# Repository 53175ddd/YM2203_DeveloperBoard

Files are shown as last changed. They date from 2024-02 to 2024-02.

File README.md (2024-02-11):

# YM2203_DeveloperBoard

YAMAHA 製 FM 音源 IC YM2203 用の SPI インターフェース開発ボード

# 部品表

| 部品番号 | 部品名 | 秋月リンク |
|:----|:----|:----:|
| C1 ~ C3 | 0.1uF | <https://akizukidenshi.com/catalog/g/g110147/> |
| C4 | 10uF | <https://akizukidenshi.com/catalog/g/g117897/> |
| C5, C6 | 47uF | <https://akizukidenshi.com/catalog/g/g110270/> |
| R1 ~ R10 | 10kΩ | <https://akizukidenshi.com/catalog/g/g125103/> |
| U1 | YM2203 | - |
| U2 | YM3014B | - |
| U3 | MCP23S17 | <https://akizukidenshi.com/catalog/g/g110644/> |
| U4, U5 | NJM4558DD | <https://akizukidenshi.com/catalog/g/g111236/> |
| U6 | 1MHz Osc | <https://akizukidenshi.com/catalog/g/g110385/> |

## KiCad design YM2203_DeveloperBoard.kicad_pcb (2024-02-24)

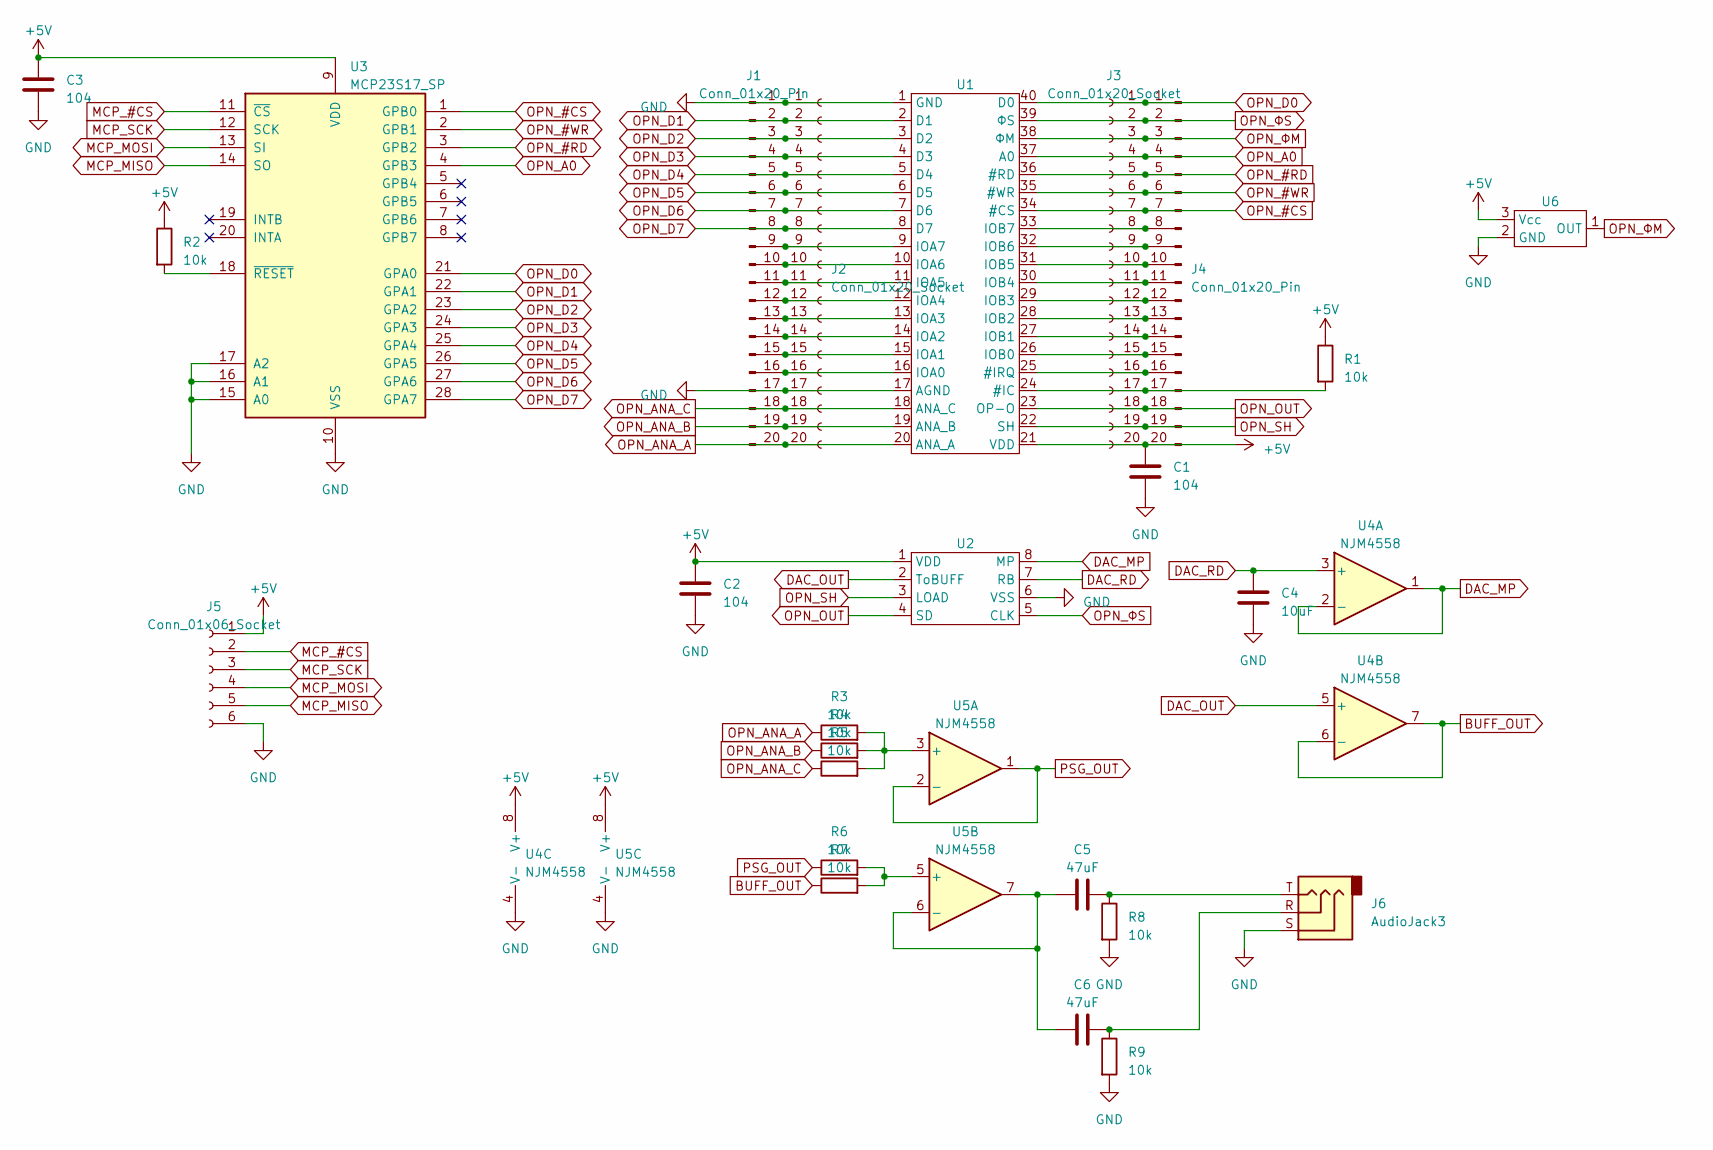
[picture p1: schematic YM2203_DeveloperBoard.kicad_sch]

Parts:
C1, C2, C3: 104; C_Disc_D5.0mm_W2.5mm_P5.00mm
C4: 10uF; CP_Radial_D6.3mm_P2.50mm
C5, C6: 47uF; CP_Radial_D6.3mm_P2.50mm
J1, J4: Conn_01x20_Pin; PinHeader_1x20_P2.54mm_Vertical
J2, J3: Conn_01x20_Socket; PinSocket_1x20_P2.54mm_Vertical
J5: Conn_01x06_Socket; PinSocket_1x06_P2.54mm_Vertical
J6: AudioJack3; Jack_3.5mm_Switronic_ST-005-G_horizontal
R1, R2, R3, R4, R5, R6, R7, R8, R9: 10k; R_Axial_DIN0207_L6.3mm_D2.5mm_P10.16mm_Horizontal
U1: DIP-40_W15.24mm_Socket
U2: DIP-8_W7.62mm_Socket
U3: MCP23S17_SP; DIP-28_W7.62mm
U4, U5: NJM4558; DIP-8_W7.62mm_Socket
U6: TO-92_Inline_Wide

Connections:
+5V: C1.1, C2.1, C3.1, J3.20, J4.20, J5.1, R1.1, R2.1, U1.21 (VDD), U2.1 (VDD), U3.9 (VDD), U4.8 (V+), U5.8 (V+), U6.3 (Vcc)
BUFF_OUT: R7.1, U4.6 (-), U4.7
DAC_MP: U2.8 (MP), U4.1, U4.2 (-)
DAC_OUT: U2.2 (ToBUFF), U4.5 (+)
DAC_RD: C4.1, U2.7 (RB), U4.3 (+)
GND: C1.2, C2.2, C3.2, C4.2, J1.1, J1.17, J2.1, J2.17, J5.6, J6.S, R8.2, R9.2, U1.1 (GND), U1.17 (AGND), U2.6 (VSS), U3.10 (VSS), U3.15 (A0), U3.16 (A1), U3.17 (A2), U4.4 (V-), U5.4 (V-), U6.2 (GND)
MCP_#CS: J5.2, U3.11 (~CS)
MCP_MISO: J5.5, U3.14 (SO)
MCP_MOSI: J5.4, U3.13 (SI)
MCP_SCK: J5.3, U3.12 (SCK)
unnamed: C5.2, J6.T, R8.1
unnamed: C6.2, J6.R, R9.1
unnamed: J1.9, J2.9, U1.9 (IOA7)
unnamed: J1.10, J2.10, U1.10 (IOA6)
unnamed: J1.11, J2.11, U1.11 (IOA5)
unnamed: J1.12, J2.12, U1.12 (IOA4)
unnamed: J1.13, J2.13, U1.13 (IOA3)
unnamed: J1.14, J2.14, U1.14 (IOA2)
unnamed: J1.15, J2.15, U1.15 (IOA1)
unnamed: J1.16, J2.16, U1.16 (IOA0)
unnamed: J3.8, J4.8, U1.33 (IOB7)
unnamed: J3.9, J4.9, U1.32 (IOB6)
unnamed: J3.10, J4.10, U1.31 (IOB5)
unnamed: J3.11, J4.11, U1.30 (IOB4)
unnamed: J3.12, J4.12, U1.29 (IOB3)
unnamed: J3.13, J4.13, U1.28 (IOB2)
unnamed: J3.14, J4.14, U1.27 (IOB1)
unnamed: J3.15, J4.15, U1.26 (IOB0)
unnamed: J3.16, J4.16, U1.25 (#IRQ)
unnamed: J3.17, J4.17, R1.2, U1.24 (#IC)
unnamed: R2.2, U3.18 (~RESET)
unnamed: R3.2, R4.2, R5.2, U5.3 (+)
unnamed: R6.2, R7.2, U5.5 (+)
unnamed: C5.1, C6.1, U5.6 (-), U5.7
OPN_#CS: J3.7, J4.7, U1.34 (#CS), U3.1 (GPB0)
OPN_#RD: J3.5, J4.5, U1.36 (#RD), U3.3 (GPB2)
OPN_#WR: J3.6, J4.6, U1.35 (#WR), U3.2 (GPB1)
OPN_A0: J3.4, J4.4, U1.37 (A0), U3.4 (GPB3)
OPN_ANA_A: J1.20, J2.20, R3.1, U1.20 (ANA_A)
OPN_ANA_B: J1.19, J2.19, R4.1, U1.19 (ANA_B)
OPN_ANA_C: J1.18, J2.18, R5.1, U1.18 (ANA_C)
OPN_D0: J3.1, J4.1, U1.40 (D0), U3.21 (GPA0)
OPN_D1: J1.2, J2.2, U1.2 (D1), U3.22 (GPA1)
OPN_D2: J1.3, J2.3, U1.3 (D2), U3.23 (GPA2)
OPN_D3: J1.4, J2.4, U1.4 (D3), U3.24 (GPA3)
OPN_D4: J1.5, J2.5, U1.5 (D4), U3.25 (GPA4)
OPN_D5: J1.6, J2.6, U1.6 (D5), U3.26 (GPA5)
OPN_D6: J1.7, J2.7, U1.7 (D6), U3.27 (GPA6)
OPN_D7: J1.8, J2.8, U1.8 (D7), U3.28 (GPA7)
OPN_OUT: J3.18, J4.18, U1.23 (OP-O), U2.4 (SD)
OPN_SH: J3.19, J4.19, U1.22 (SH), U2.3 (LOAD)
OPN_ΦM: J3.3, J4.3, U1.38 (ΦM), U6.1 (OUT)
OPN_ΦS: J3.2, J4.2, U1.39 (ΦS), U2.5 (CLK)
PSG_OUT: R6.1, U5.1, U5.2 (-)

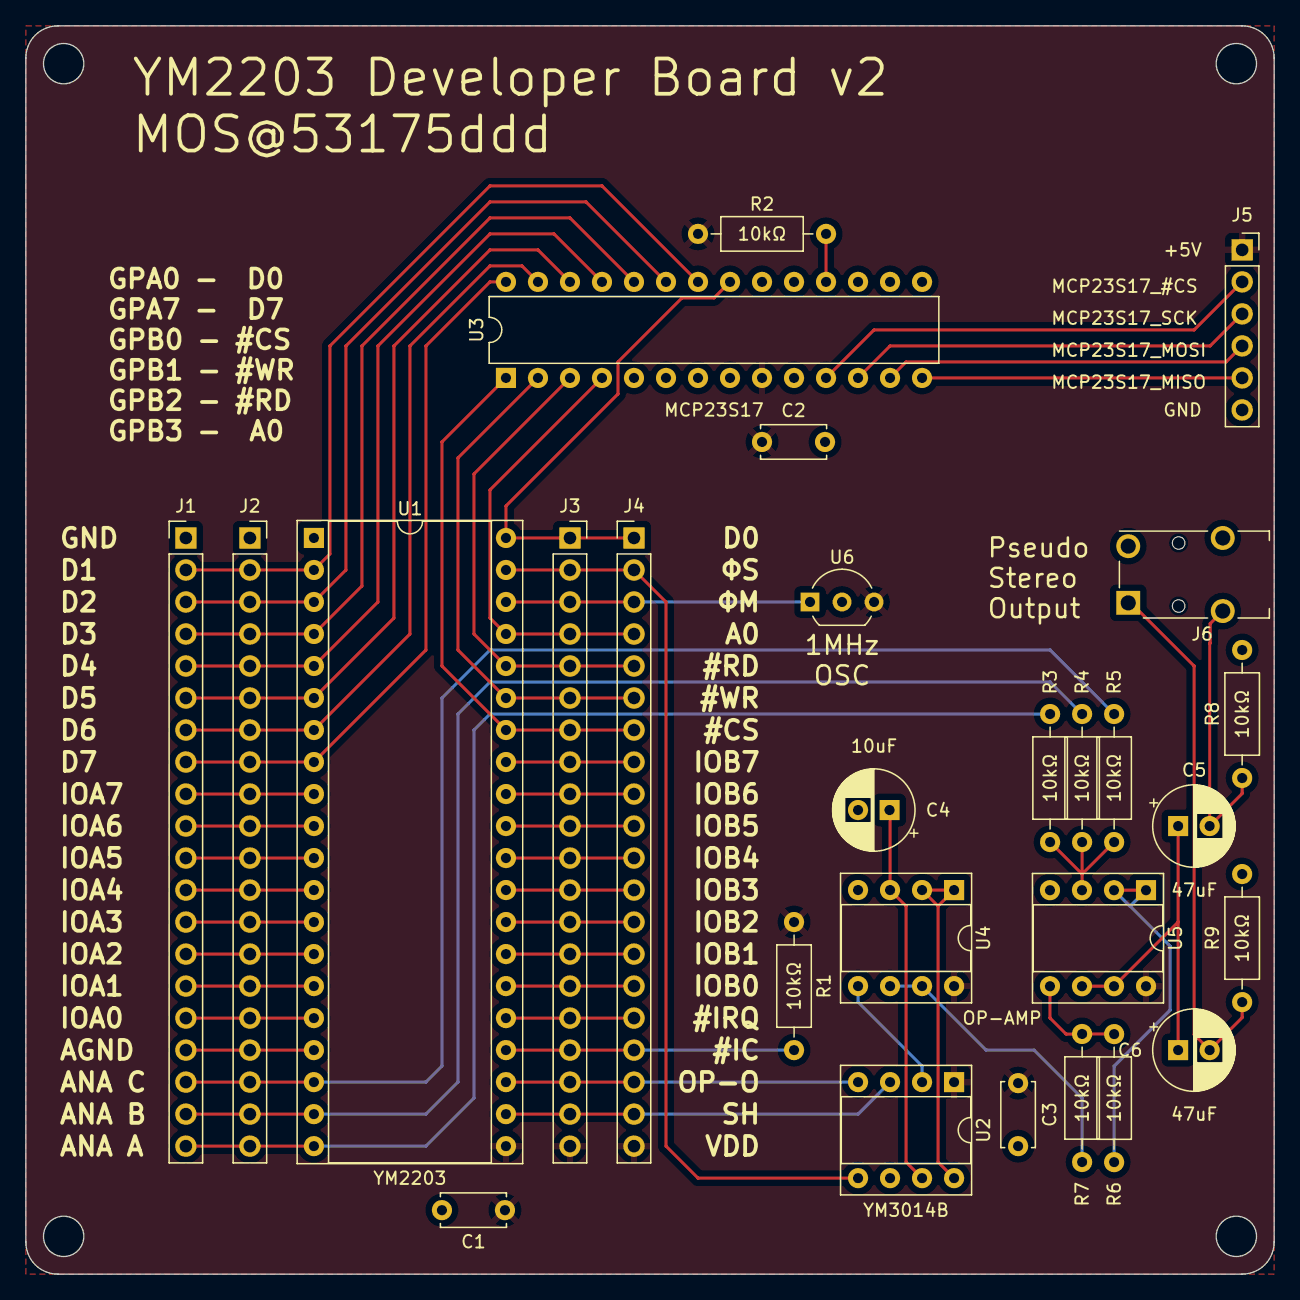
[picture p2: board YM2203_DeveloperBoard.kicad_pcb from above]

Board: 2 copper layers, 99.1 x 99.1 mm, 27 parts (0 on the bottom side), 54 nets.

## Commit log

2024-01-18 add bom
2024-02-05 U5 の電源未配線を修正
    [YM2203_DeveloperBoard.kicad_pcb]
2024-02-06 基板整形，シルク印刷追記修正
    [YM2203_DeveloperBoard.kicad_pcb]
2024-02-11 部品表更新
2024-02-24 update to v2
    [YM2203_DeveloperBoard.kicad_pcb]
2024-03-28 タグを修正
    [YM2203_DeveloperBoard.kicad_sch]
